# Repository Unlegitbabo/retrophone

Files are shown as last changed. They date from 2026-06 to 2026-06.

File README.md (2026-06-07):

# Smart Retro Telefon – Projekt-Dokumentation

## 1. Einführung

Dieses Projekt beschreibt den Umbau eines klassischen analogen Telefons zu einem modernen **Smart Retro Telefon**.
Das Ziel ist es, den originalen Look, die Mechanik und die Haptik zu erhalten, während im Inneren moderne Elektronik
für Bluetooth, WLAN, Sprachsteuerung und Smart-Home-Integration sorgt.

Das Telefon funktioniert **eigenständig**, kann aber durch einen externen Raspberry Pi massiv erweitert werden.

---

## 2. Feature-Set

### Basis-Funktionen (lokal, ohne Netzwerk)
- Bluetooth-Telefonie (HFP)
- Bluetooth-Musik (A2DP)
- Musik hören über internen Lautsprecher ohne Abheben
- Telefonieren über originalen Hörer
- Mechanische Klingel für Anrufe
- Wecker mit Klingel
- Abheben / Auflegen erkennt Anrufe
- Wählscheibe zur Nummern- und Funktionswahl

### Erweiterte Funktionen (WLAN)
- WLAN-Anbindung (ESP32)
- Steuerung von Philips Hue
- Sprachsteuerung (Wake Word + Befehle)
- Zeit- und Szenensteuerung
- OTA-Firmware-Updates

### Externe Erweiterung (Raspberry Pi)
- Home Assistant
- Node-RED / Automationen
- Erweiterte Sprachlogik
- Logging & Statistik
- Smart-Home-Zentrale

---

## 3. Systemarchitektur (Übersicht)

```
Smartphone
   ⇅ Bluetooth
┌───────────────────┐
│       ESP32       │
│  WLAN + Bluetooth │
└───┬─────────┬─────┘
    │         │
 Audio Out   Audio In
    │         │
┌───▼───┐   ┌─▼─────────┐
│Amp(s) │   │ Mikrofone │
└───┬───┘   └───────────┘
    │
┌───▼──────────┐
│ Lautsprecher │
└──────────────┘
    │
┌───▼──────────┐
│ Klingel      │
└──────────────┘

ESP32 ⇄ WLAN ⇄ Raspberry Pi (optional)
```

---

## 4. Zentrale Komponenten

### 4.1 ESP32 – Hauptcontroller

**Funktion**
- Steuerzentrale des Telefons
- Bluetooth & WLAN
- Audio-Verarbeitung
- GPIO-Logik

**Technische Daten**
- Betriebsspannung: 3.3 V
- Stromaufnahme:
  - Idle: ~80 mA
  - WLAN + BT aktiv: bis 300 mA
- CPU: Dual-Core, 240 MHz

---

### 4.2 Audio-System

#### Lautsprecher
- Impedanz: 4 Ω
- Leistung: 3–5 W
- Einsatz:
  - Musik
  - Klingel
  - Wecker

#### Verstärker (MAX98357A)
- Eingang: I2S (digital)
- Versorgung: 5 V
- Ausgangsleistung: bis 3 W @ 4 Ω
- Wirkungsgrad: >85 %

---

### 4.3 Mikrofone

#### Internes Mikrofon (Sprachsteuerung)
- Typ: I2S Mikrofon (INMP441)
- Spannung: 3.3 V
- Strom: ~10 mA
- Sampling: 16 kHz

#### Hörer-Mikrofon (Telefonie)
- Typ: Elektret-Mikrofon + MAX9814
- Spannung: 3–5 V
- Strom: ~3 mA
- Auto-Gain

---

### 4.4 Mechanische Klingel

**Original-Zustand**
- Benötigt Wechselstrom
- Ursprünglich ca. 60–90 V AC

**Neue Ansteuerung**
- Versorgung: 12 V DC
- Ansteuerung über H-Bridge
- Strom: bis 1 A kurzzeitig
- Leistung: max. ~12 W (impulsartig)

---

## 5. Stromversorgung

### Netzteil
- Ausgang: 12 V DC
- Strom: 3 A
- Leistung: 36 W

### Spannungswandler
- 12 V → 5 V (Verstärker)
- 5 V → 3.3 V (ESP32)

**Grundregel**
> Falsche Spannung zerstört Bauteile schneller als zu viel Strom.

---

## 6. Bedienelemente

### Wählscheibe
- Impulswahl
- 1 Puls = Ziffer 1
- 10 Pulse = Ziffer 0
- Auswertung per GPIO-Interrupt

### Hook-Switch
- Mechanischer Schalter
- Erkennung:
  - Aufgelegt
  - Abgehoben

---

## 7. Raspberry Pi (extern)

**Aufgabe**
- Home Assistant
- Philips Hue
- Sprachverarbeitung
- Automationen

**Verbindung**
- WLAN
- HTTP / MQTT

**Strom**
- 5 V / ~2 A
- Nicht im Telefon verbaut

---

## 8. Software-Architektur

### ESP32 (lokal)
- Audio-Routing
- Bluetooth-Handling
- GPIO-Events
- Wecker & Klingel
- Basis-Sprachbefehle

### Raspberry Pi (optional)
- Szenen
- Smart-Home-Logik
- Sprachintelligenz
- Zeitpläne

---

## 9. Entwicklungsumgebung

- Linux Laptop
- Arduino IDE oder PlatformIO
- USB-Verbindung zum ESP32
- Serielles Debugging

---

## 10. Projektphasen

### Phase 1 – Basis
- ESP32
- Lautsprecher
- Bluetooth Musik

### Phase 2 – Retro
- Wählscheibe
- Klingel
- Wecker

### Phase 3 – Smart
- WLAN
- Raspberry Pi
- Sprachsteuerung

---

## 11. Ziel

Ein funktionales, erweiterbares und langlebiges Smart-Objekt,
das Technik und Nostalgie verbindet – ohne Cloud-Zwang und ohne
Verlust des originalen Charakters.

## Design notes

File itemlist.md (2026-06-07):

# 🧾 Smart Retro Telefon – BOM & Werkzeugliste (Links geprüft und korrigiert)

---

## 1 Stückliste (BOM)

### 1.1 Zentrale Steuerung

| Bauteil | Menge | Zweck | Link |
|---|---:|---|---|
| ESP32 DevKit (ESP32 WROOM-32D / DevKit) | 1 | Hauptcontroller | https://de.aliexpress.com/item/1005008503831020.html |
| USB-Kabel (datenfähig) | 1 | Programmierung |  |

---

### 1.2 Audio-Ausgabe

| Bauteil | Menge | Zweck | Link |
|---|---:|---|---|
| I2S Audio Verstärker MAX98357A | 2 | Lautsprecher + Hörer | (Link in deiner Liste nicht sicher verifiziert – bitte MAX98357A-Link prüfen/ersetzen) |
| Mini-Lautsprecher 4 Ω, 3–5 W | 1 | Freisprechen / Musik | (nicht verifiziert – bitte passenden Lautsprecher-Link ergänzen) |
| Lautsprecherkabel | ~1 m | Audio-Verbindung | (siehe Kabel-Links unten) |

---

### 1.3 Mikrofone

| Bauteil | Menge | Zweck | Link |
|---|---:|---|---|
| I2S Mikrofon (INMP441 / SPH0645) | 1 | Sprachsteuerung | (nicht verifiziert – bitte passenden INMP441-Link ergänzen) |
| Elektret-Mikrofon | 1 | Telefonie | (nicht verifiziert – bitte passenden Link ergänzen) |
| Mikrofon-Vorverstärker MAX9814 | 1 | Pegelanpassung | https://de.aliexpress.com/item/1005005802800683.html |
| Mikrofon-/Signalkabel (geschirmt empfohlen) | ~1 m | Mikrofonverkabelung | https://de.aliexpress.com/item/1005005929665600.html |

---

### 1.4 Klingel-Ansteuerung

| Bauteil | Menge | Zweck | Link |
|---|---:|---|---|
| H-Bridge / Motortreiber (DRV8871 / L298N) | 1 | Klingelbetrieb | https://de.aliexpress.com/item/1005010441923707.html *(nicht verifiziert)* |
| Original Telefon-Glocke | 1 | Klingeln | vorhanden |
| Freilaufdiode (falls nötig) | 1 | Schutz | (nicht in deinen Links verifiziert enthalten) |

---

### 1.5 Stromversorgung

| Bauteil | Menge | Zweck | Link |
|---|---:|---|---|
| Netzteil 12 V / 3 A | 1 | Hauptversorgung | (nicht verifiziert – bitte Netzteil-Link ergänzen) |
| Step-Down Wandler (LM2596) | 1–2 | 12 V → 5 V | https://de.aliexpress.com/item/1005006133320882.html |
| Schraubklemmen (KF128, 2.54mm) | Set | Anschluss / Verteilen | https://de.aliexpress.com/item/1005002549483233.html |

---

### 1.6 Eingaben & Bedienung

| Bauteil | Menge | Zweck | Link |
|---|---:|---|---|
| Wählscheibe | 1 | Nummern / Befehle | vorhanden |
| Hook-Switch | 1 | Hörer-Erkennung | vorhanden |
| Taster (optional) | 1–2 | Pairing / Reset | https://de.aliexpress.com/item/1005010493585656.html *(Sortiment)* |
| Status-LED | 1 | Betriebsstatus | https://de.aliexpress.com/item/1005003483614644.html *(LEDs)* |

---

### 1.7 Mechanik & Montage

| Bauteil | Menge | Zweck | Link |
|---|---:|---|---|
| Abstandshalter (M2/M2.5/M3…) | Set | Befestigung | https://de.aliexpress.com/item/1005007498157463.html |
| Schrumpfschlauch | Set | Isolation | https://de.aliexpress.com/item/1005008146302901.html |

---

### 1.8 Verkabelung & Steckverbinder

| Bauteil | Menge | Zweck | Link |
|---|---:|---|---|
| DuPont Connector Kit 2.54mm | Set | Steckverbinder | https://de.aliexpress.com/item/1005010487181911.html |
| RV flexible Leitung 0.75mm² (einadrig, 5m) | 1 | 12V/Power (je nach Bedarf) | https://de.aliexpress.com/item/4000824335983.html |
| RVB 2-adriges Kabel (rot/schwarz) | 1 | 5V/12V Zuleitung | https://de.aliexpress.com/item/1005005908897505.html |

---

## 2 Werkzeugliste (korrigiert)

| Werkzeug | Zweck | Link |
|---|---|---|
| Lötstation (C245/JBC-kompatibel, z.B. „TC22“) | Löten | https://de.aliexpress.com/item/1005006397758007.html |
| Lötzinn (0.8 / 1.0 mm) | Löten | https://de.aliexpress.com/item/1005008618276811.html |

> Weitere Werkzeuge (Multimeter, Seitenschneider, Abisolierer, Schraubendreher) hast du in deiner Liste – dafür liegen in deinen Links aktuell **keine verifizierten** Artikel-IDs vor.

---

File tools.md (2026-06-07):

## 1. Werkzeugliste

### 1.1 Unbedingt notwendig

| Werkzeug | Zweck |
|---|---|
| Regelbarer Lötkolben | Elektronik löten |
| Lötzinn | Elektrische Verbindungen |
| Multimeter | Spannung / Durchgang messen |
| Seitenschneider | Kabel kürzen |
| Abisolierzange | Kabel vorbereiten |
| Schraubendreher-Set | Telefon öffnen |
| Pinzette | Feinarbeiten |

---

### 1.2 Sehr empfohlen

| Werkzeug | Zweck |
|---|---|
| Dritte Hand / Platinenhalter | entspanntes Löten |
| Heißklebepistole | mechanische Fixierung |
| Heißluftfön | Schrumpfschlauch |
| Mini-Bohrmaschine / Dremel | Anpassungen |
| Logic Analyzer (optional) | Wählscheibe debuggen |

---

### 1.3 Software-Werkzeuge

| Tool | Zweck |
|---|---|
| Linux Laptop | Entwicklung |
| Arduino IDE oder PlatformIO | ESP31 Programmierung |
| USB-Treiber (falls nötig) | Serielle Verbindung |
| Git (optional) | Versionierung |

---

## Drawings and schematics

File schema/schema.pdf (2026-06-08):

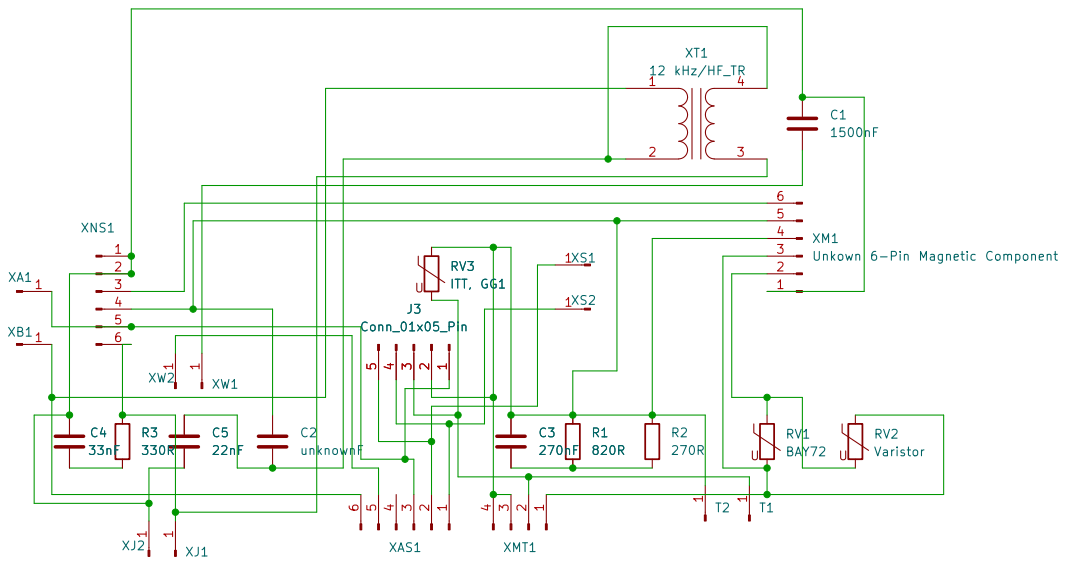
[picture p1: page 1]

Size: A4 | Rev:
KiCad E.D.A. 10.0.3 | Id: 1/1

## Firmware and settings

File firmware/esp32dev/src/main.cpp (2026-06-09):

#include <Arduino.h>
#include "rotarydial/RotaryDial.h"
#include "Debug.h"
#include "Pins.h"
#include "phone/Phone.h"


// ----------------- Setup ----------------- //

void setupPins();
void setLed(bool an);
void blinkLed(int dauer);

void setup() {
  Serial.begin(115200);
  
  setupPins();
  setupPhone();
}

void setupPins() {
  DEBUG_PRINTLN("System startet");
  pinMode(PIN_LED, OUTPUT);
}

// ----------------- Main ----------------- //

void loop() {
  blinkLed(500);
  
  updatePhone();



}


// ----------------- Funktion ----------------- //


void setLed(bool an) {
  digitalWrite(PIN_LED, an ? HIGH : LOW);
}

void blinkLed(int dauer) {
  static unsigned long lastChange = 0;
  static bool ledState = false;

  unsigned long now = millis();

  if (now - lastChange >= dauer) {
    ledState = !ledState;
    setLed(ledState);
    lastChange = now;
  }
}

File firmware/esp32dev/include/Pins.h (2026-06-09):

#pragma once

constexpr int PIN_DIAL_NUMBER = 32;
constexpr int PIN_DIAL_ACTIVE = 33;
constexpr int PIN_HOOK = 19;  // hook-switch: handset on/off the cradle
constexpr int PIN_LED = 2;

#define I2S_BCLK 26
#define I2S_LRC 25
#define I2S_DIN 27

#define PIN_MIC_ADC 34

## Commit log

2026-06-09 AudioOut Stable
    [schema_esp32.kicad_pcb, schema_esp32.kicad_sch]
2026-06-09 mic test
    [schema_esp32.kicad_sch]
2026-06-09 adjusted pin settings to reflect current state
2026-06-09 chore: remove WAV playback and dead code
    - Delete legacy Blink .ino sketch and all WAV assets
    - Drop SPIFFS/LittleFS filesystem (no longer needed; frees flash)
    - Strip dead PhoneNumber subsystem, unused currentNumber, TEST_PIN
    - Gate AudioIn serial output behind DEBUG
    - Tidy Pins.h comments and README typo
    [AudioIn.cpp, AudioOut.cpp, Phone.cpp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]
2026-06-09 feat(bluetooth): add A2DP music sink with I2S mode switching
    - Add ESP32-A2DP library + min_spiffs partition for the BT stack
    - New audio/bluetooth module owns BT mode and the I2S handoff between
    the local tone engine and the Bluetooth sink
    - Dial 9 enters Bluetooth music mode (advertises as 'RetroPhone');
    dialing any digit exits and restores local tone/melody audio
    - Structured as a generic BT manager so HFP (calls) can be layered on
2026-06-09 feat(hookswitch): detect handset on/off cradle
    - New hookswitch module: debounced read on GPIO 19 (INPUT_PULLUP),
    exposing isOffHook() plus one-shot lift/place edge queries
    - Phone state machine logs off-hook (ready to dial/answer) and treats
    on-hook as hang up -> returns to PHONE_IDLE (also exits Bluetooth)
    - Polarity set via HOOK_OFFHOOK_LEVEL constant; flip if wiring inverts
    [Phone.cpp, Pins.h]
